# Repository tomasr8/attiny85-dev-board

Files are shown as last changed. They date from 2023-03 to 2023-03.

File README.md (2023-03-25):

# attiny85 development board

<image src="assets/assembled/1.jpg">

<p align="middle">
    <image src="assets/assembled/2.jpg" width="49%">
    <image src="assets/assembled/3.jpg" width="49%">
    <image src="assets/assembled/4.jpg" width="49%">
    <image src="assets/assembled/5.jpg" width="49%">
</p>

## Features

- All 6 GPIOs from the attiny available (marked 0-5 which corresponds to PB0-PB5 on the attiny)
- 5V output (direct from USB)
- 3V3 output (via AMS1117 voltage regulator)
- Power LED
- Onboard LED connected to PB1
- USB-A connector

The schematic is based on the [Digispark attiny85 devboard](assets/digispark-schematic.pdf).

## Why?

To learn more about electronics and PCB design and also because the Digispark boards don't have a 3V3 output. This board also uses USB-A instead of Micro USB so I don't need any extra cable to connect to my laptop. 

## Custom footprints

I use a custom footprint for the USB connector. You'll need to add it to your Kicad footprint library. It's a standard USB-A male connector with through hole connections for easier soldering (exact type is `MOLEX 48037-0001`, available on aliexpress).

<p align="center">
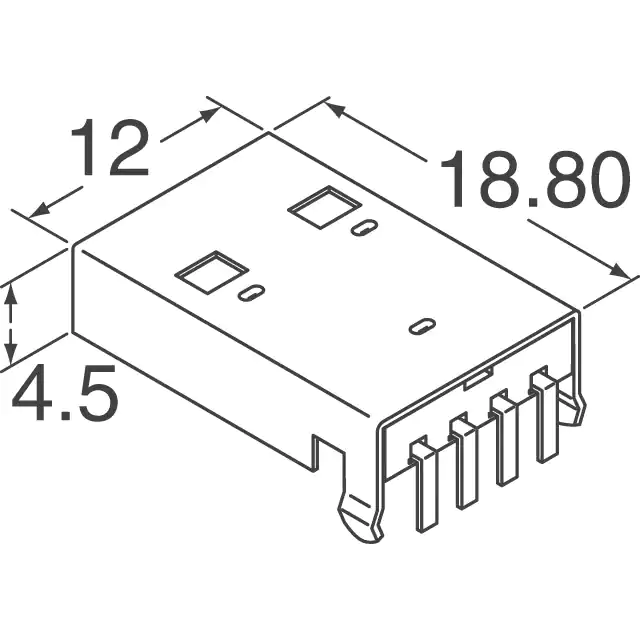
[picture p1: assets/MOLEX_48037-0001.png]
    
</p>

## Bill of materials

All of these components can be easily sourced from aliexpress.

- 2x 470Ω (or similar) resistor (for LEDs)
- 1x Green SMD 1206 LED
- 1x Red SMD 1206 LED
- 2x 66Ω (or similar) resistor (for USB)
- 1x 1K5Ω (or similar) resistor (for USB)
- 2x 3V6 Zener diode (for USB)
- 1x AMS1117 SMD voltage regulator (for 3V3 output)
- 1x IC DIP socket 10-pin (for the attiny)
- 1x attiny85 DIP chip
- 1x 2x5 male or female pin header (breakout connectors)
- 1x USB-A male connector, type MOLEX 48037-0001

## Soldering

I'm not great at soldering SMD components so I recommend starting with those. That would be the LEDs and the voltage regulator. After that you can continue with the chip socket and the pin header. You can finish off with the resistors/diodes and the USB connector.

## Programming

The attiny chip needs to be flashed with a bootloader so that you can use it without a programmer (like an Arduino board).
Here are two tutorials that I used to get mine working (you're gonna need an Arduino board to burn the bootloader):

- https://github.com/Jasdoge/Attiny85-Bootloader-Tutorial
- https://circuitdigest.com/microcontroller-projects/attiny85-ic-programming-through-usb-using-digispark-bootloader

These tutorials use the micronucleus bootloader used by the Digispark attiny boards.

There is an onboard LED hardwired to PB1 so you can get your `blink` sketch running without any extra hardware ;)

## Schematics

<p align="center">
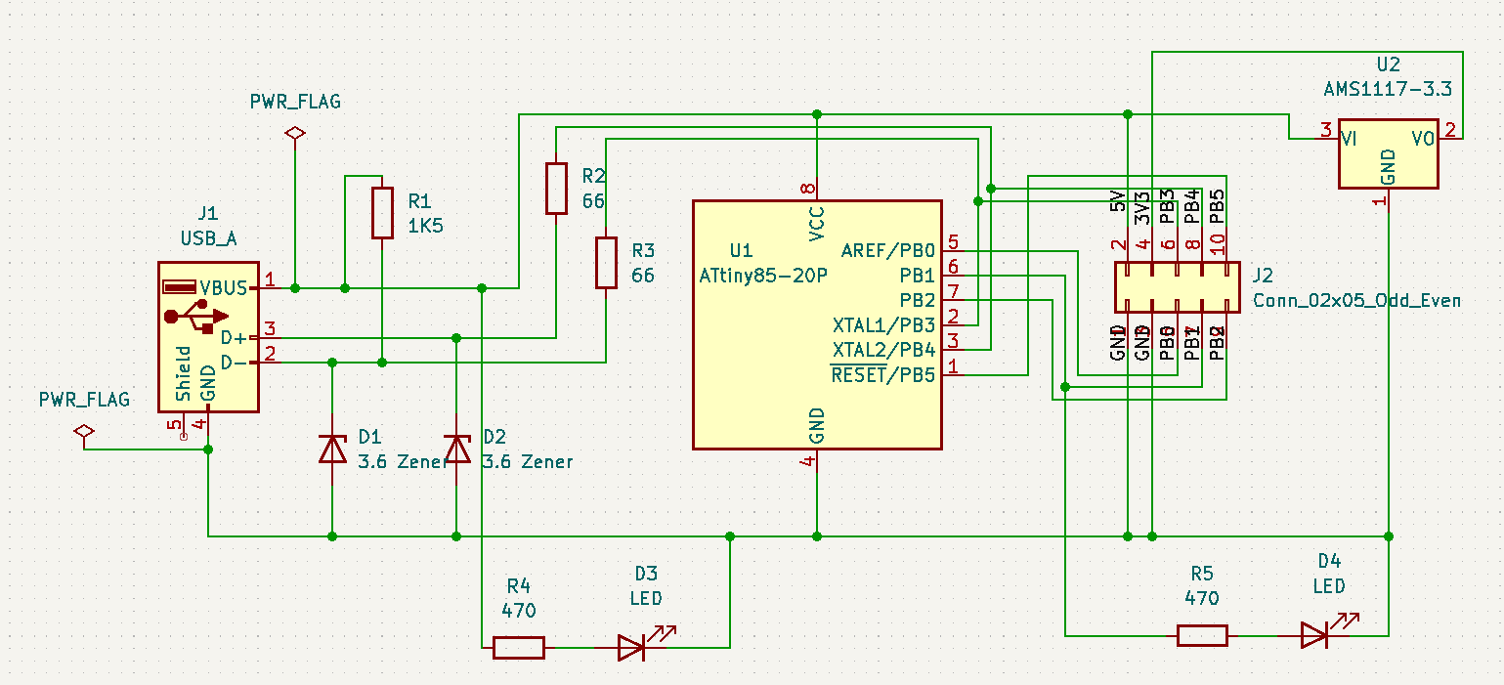
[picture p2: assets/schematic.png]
    
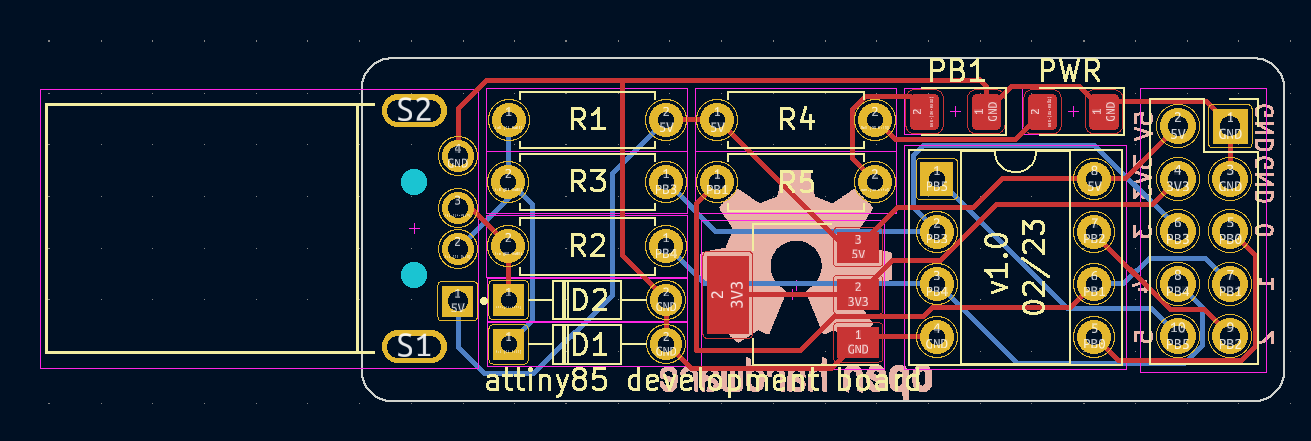
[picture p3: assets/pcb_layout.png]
    
</p>

## Renders

<p align="center">
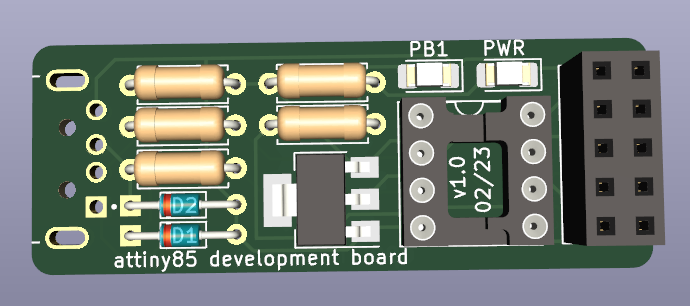
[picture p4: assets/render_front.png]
    
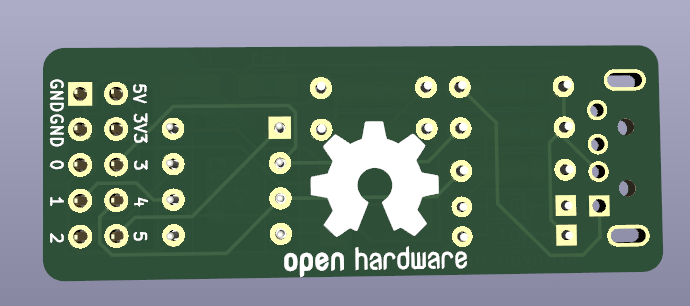
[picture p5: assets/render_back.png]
    
</p>

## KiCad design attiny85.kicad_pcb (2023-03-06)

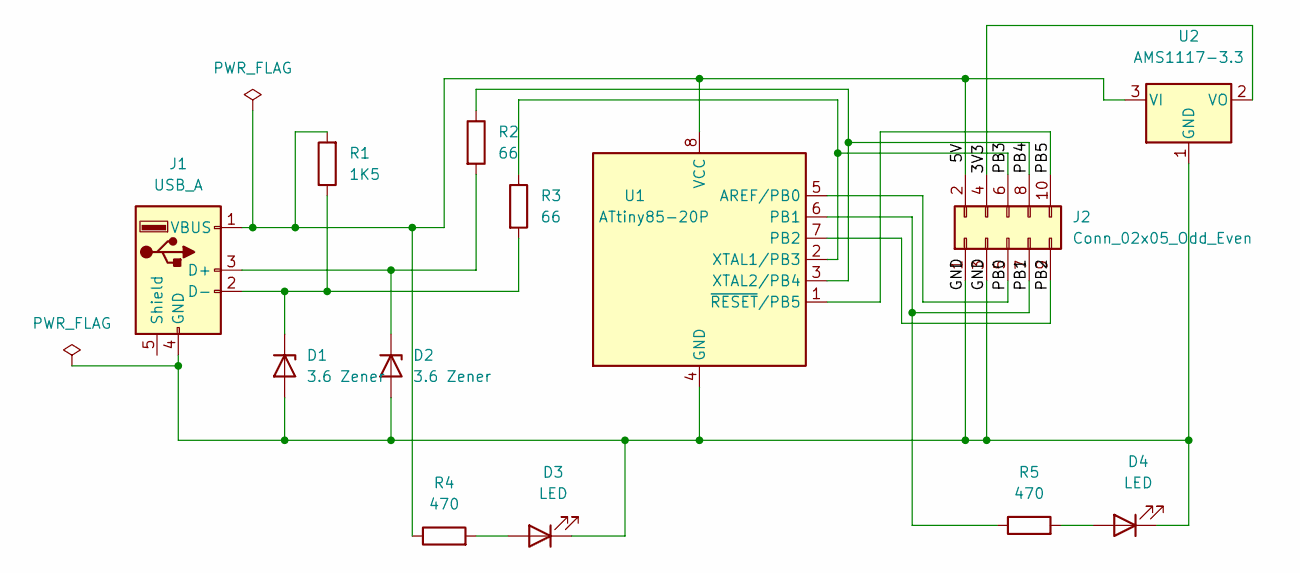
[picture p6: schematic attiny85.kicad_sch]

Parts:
D1, D2: 3.6 Zener; D_DO-34_SOD68_P7.62mm_Horizontal
D3, D4: LED; LED_1206_3216Metric_Pad1.42x1.75mm_HandSolder
J1: USB_A; MOLEX_48037-0001
J2: Conn_02x05_Odd_Even; PinSocket_2x05_P2.54mm_Vertical
R1: 1K5; R_Axial_DIN0207_L6.3mm_D2.5mm_P7.62mm_Horizontal
R2, R3: 66; R_Axial_DIN0207_L6.3mm_D2.5mm_P7.62mm_Horizontal
R4, R5: 470; R_Axial_DIN0207_L6.3mm_D2.5mm_P7.62mm_Horizontal
U1: ATtiny85-20P; DIP-8_W7.62mm_Socket
U2: AMS1117-3.3; SOT-223-3_TabPin2

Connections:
/3V3: J2.4, U2.2 (VO)
/5V: J1.1 (VBUS), J2.2, R1.2, R4.1, U1.8 (VCC), U2.3 (VI)
/GND: D1.2 (A), D2.2 (A), D3.1 (K), D4.1 (K), J1.4 (GND), J2.1, J2.3, U1.4 (GND), U2.1 (GND)
/PB0: J2.5, U1.5 (AREF/PB0)
/PB1: J2.7, R5.1, U1.6 (PB1)
/PB2: J2.9, U1.7 (PB2)
/PB3: J2.6, R3.1, U1.2 (XTAL1/PB3)
/PB4: J2.8, R2.1, U1.3 (XTAL2/PB4)
/PB5: J2.10, U1.1 (~RESET/PB5)
unnamed: D1.1 (K), J1.2 (D-), R1.1, R3.2
unnamed: D2.1 (K), J1.3 (D+), R2.2
unnamed: D3.2 (A), R4.2
unnamed: D4.2 (A), R5.2

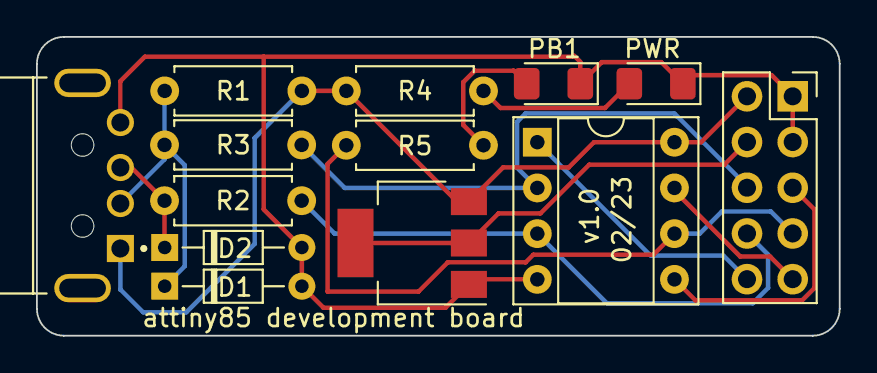
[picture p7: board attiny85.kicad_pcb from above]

Board: 2 copper layers, 44.6 x 16.6 mm, 13 parts (0 on the bottom side), 13 nets.

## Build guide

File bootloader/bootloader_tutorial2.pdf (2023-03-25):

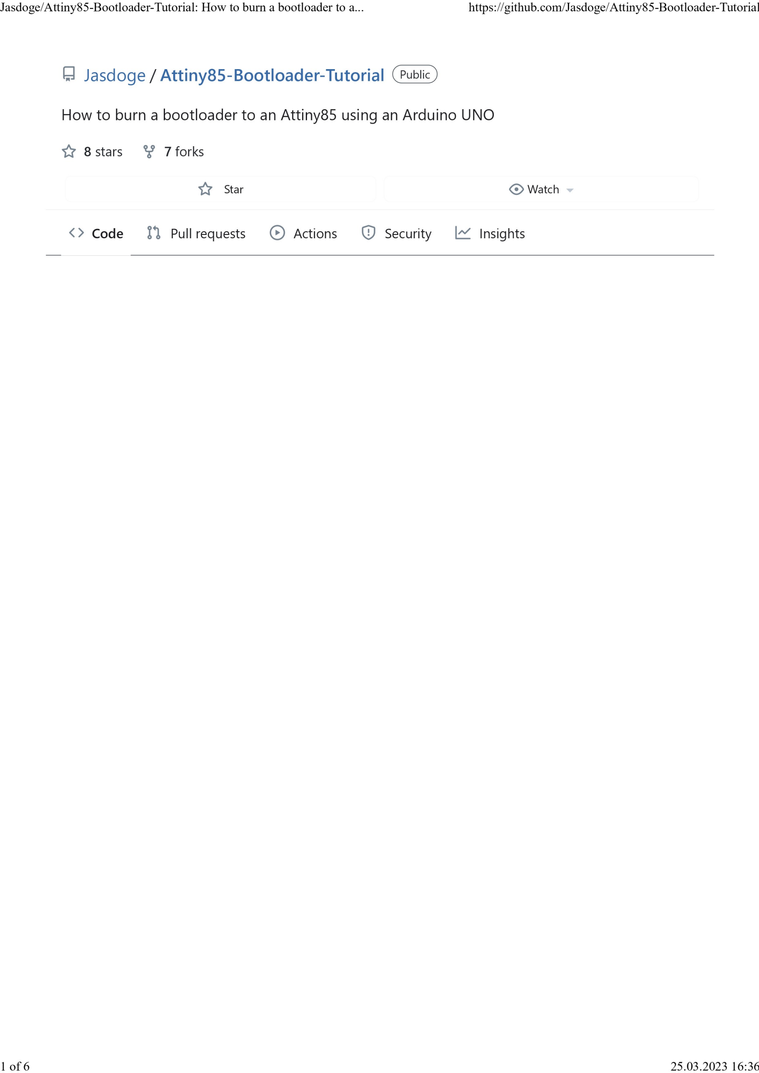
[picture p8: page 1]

Jasdoge / Attiny85-Bootloader-Tutorial Public

How to burn a bootloader to an Attiny85 using an Arduino UNO

### 8 stars 7 forks

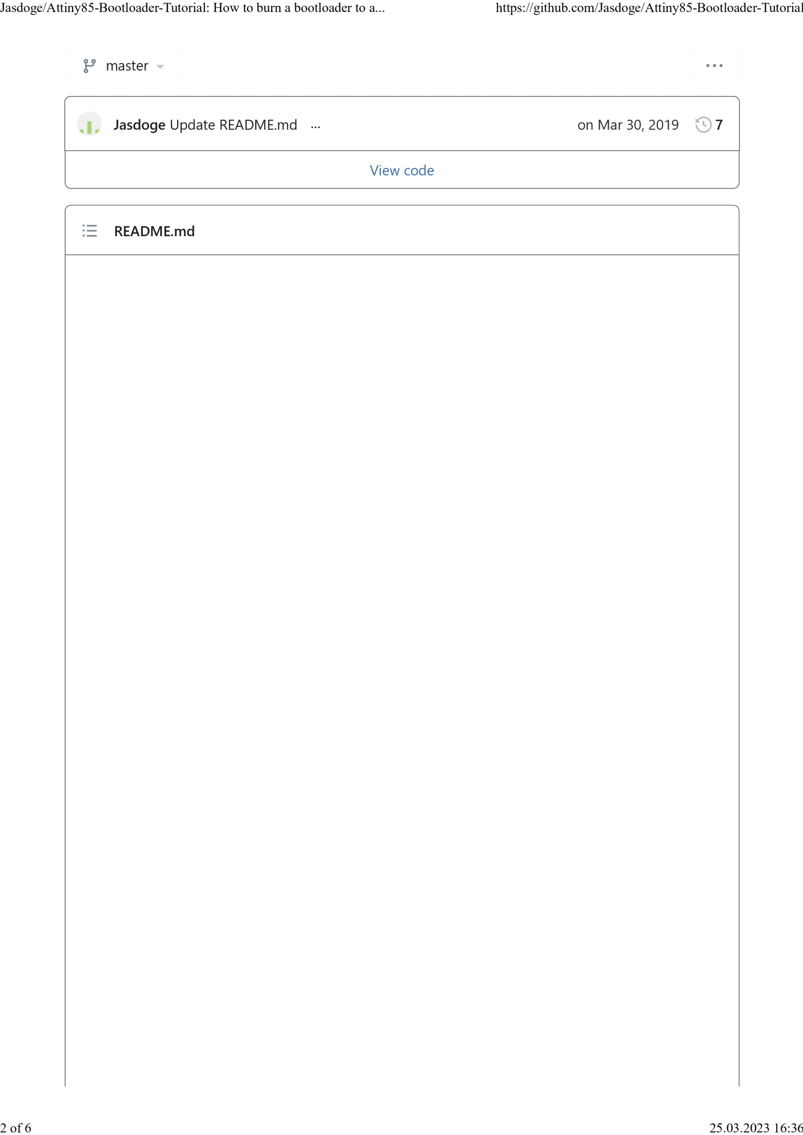
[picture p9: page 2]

View code

Jasdoge/Attiny85-Bootloader-Tutorial: How to burn a bootloader to a... | https://github.com/Jasdoge/Attiny85-Bootloader-Tutorial
3 of 6 | 25.03.2023 16:36

# Attiny85-Bootloader-Tutorial

I recently got one of those cheap chinese attiny USB socket boards and discovered that in order to use the arduino IDE, you need to burn a bootloader onto it. I found a few tutorials online, but a lot of them felt incomplete or included redundant steps.

Video:

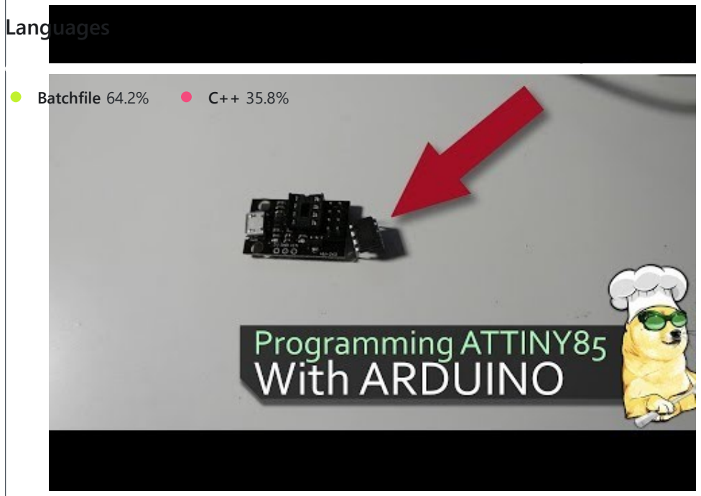
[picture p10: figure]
Languages; Batchfile 64.2%

Here's how to burn a bootloader to an Attiny85 using an Arduino UNO:

### 1. Install the Arduino IDE https://www.arduino.cc/en/Main/Software 2. Install the digistump drivers https://github.com/digistump/DigistumpArduino

/releases
3. Open the arduino IDE and go to file > preferences.

### 4. Add http://digistump.com/package_digistump_index.json to the additional

boards manager URLs.
5. Go to tools > board > boards manager.

Releases

No releases published

Packages

No packages published

4 of 6 | 25.03.2023 16:36

6. Search for digistump, and install Digistump AVR boards.
7. Connect your arduino uno via USB.

### 8. Go to file > examples > 11. ArduinoISP > ArduinoISP to open the ArduinoISP

sketch.
9. Hit the arrow button to upload it to your arduino.

### 10. Unplug your arduino and get your Attiny85, breadboard, some wires, and a 10uF

capacitor.

### 11. Wire the following:

Attiny physical pin | Arduino GPIO/Pin
1 10
4 GND
5 11
6 12
7 13
8 5V

Also connect a 10uF capacitor between arduino RST and arduino GND. If using an electrolytic capacitor, put anode on RST and cathode on GND.

### 12. Connect your arduino again via USB and go into the Arduino IDE. Check what

port it's connected to. In my case it's COM3.

### 13. Edit the burn_attiny85_bootloader.bat file from this repository (right click and

edit). Edit the part that says -PCOM22 to match your port. In my case since I use COM3, I'll edit it to -PCOM3

### 14. Save and copy both the bat file and t85_default.hex to your arduino install

directory.
15. Run the bat file, and it should now burn the bootloader to your attiny85.

# Uploading via arduino

After adding the bootloader, you can now upload via arduino. There's a testsketch in this repo if you just want to blink the debug LED.

1. Write your sketch as usual.

### 2. Connect your attiny to your USB socket board. But don't plug it to the computer

yet.

5 of 6 | 25.03.2023 16:36

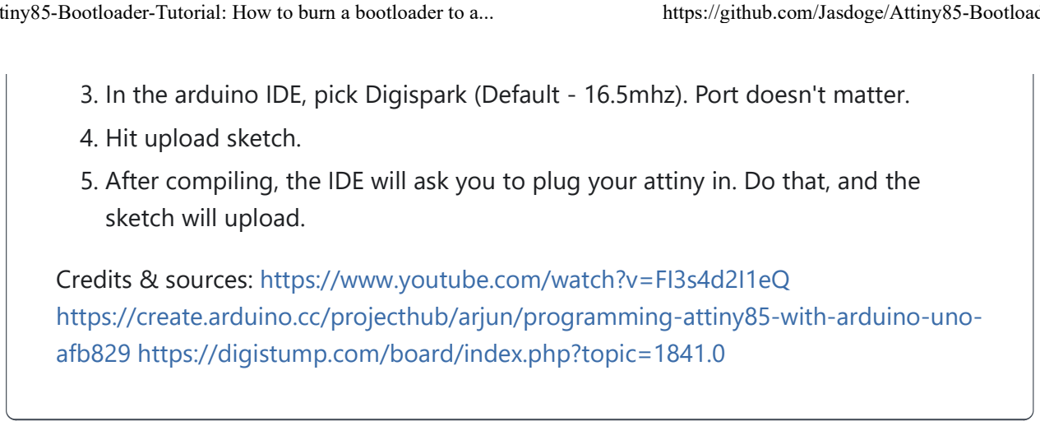
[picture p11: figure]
4. Hit upload sketch.; sketch will upload.; Credits & sources: https://www.youtube.com/watch?v=FI3s4d2I1eQ https://create.arduino.cc/projecthub/arjun/programming-attiny85-with-arduino-uno- afb829 https://digistump.com/board/index.php?topic=1841.0

3. In the arduino IDE, pick Digispark (Default - 16.5mhz). Port doesn't matter.

### 5. After compiling, the IDE will ask you to plug your attiny in. Do that, and the

6 of 6 | 25.03.2023 16:36

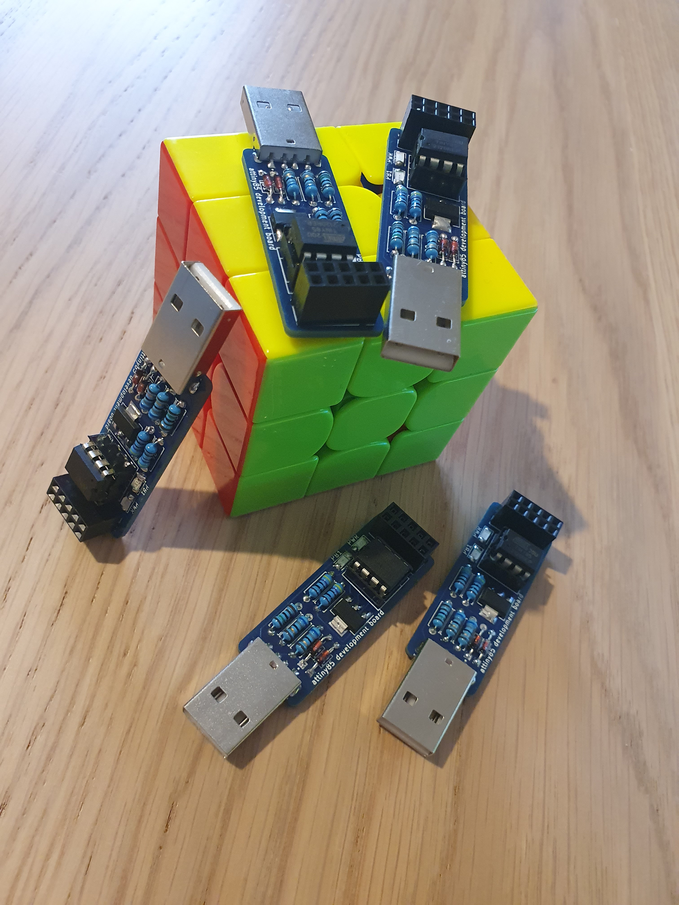
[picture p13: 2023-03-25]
assets/assembled/1.jpg

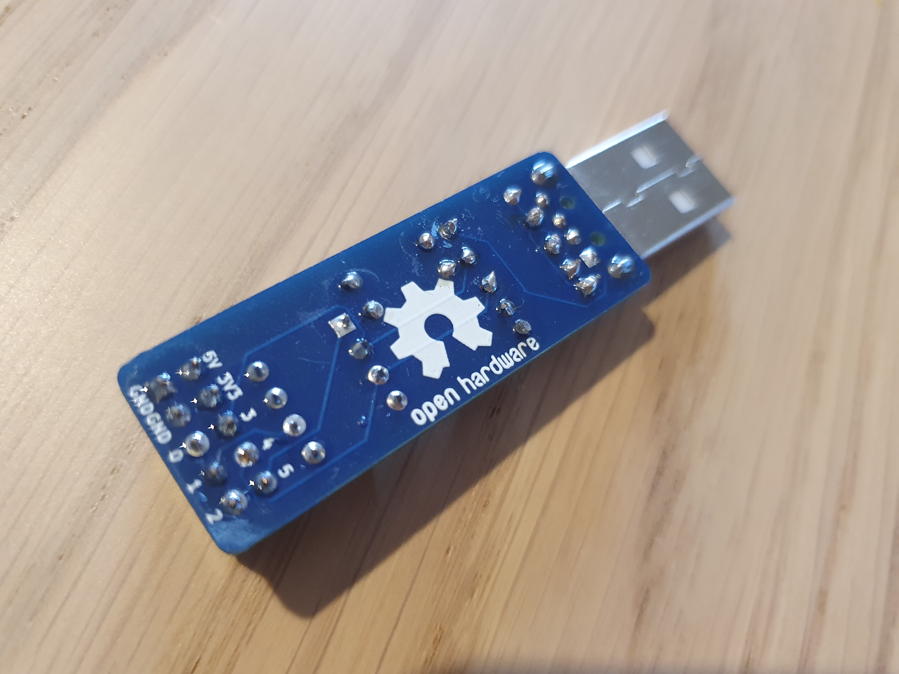
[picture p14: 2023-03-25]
assets/assembled/3.jpg

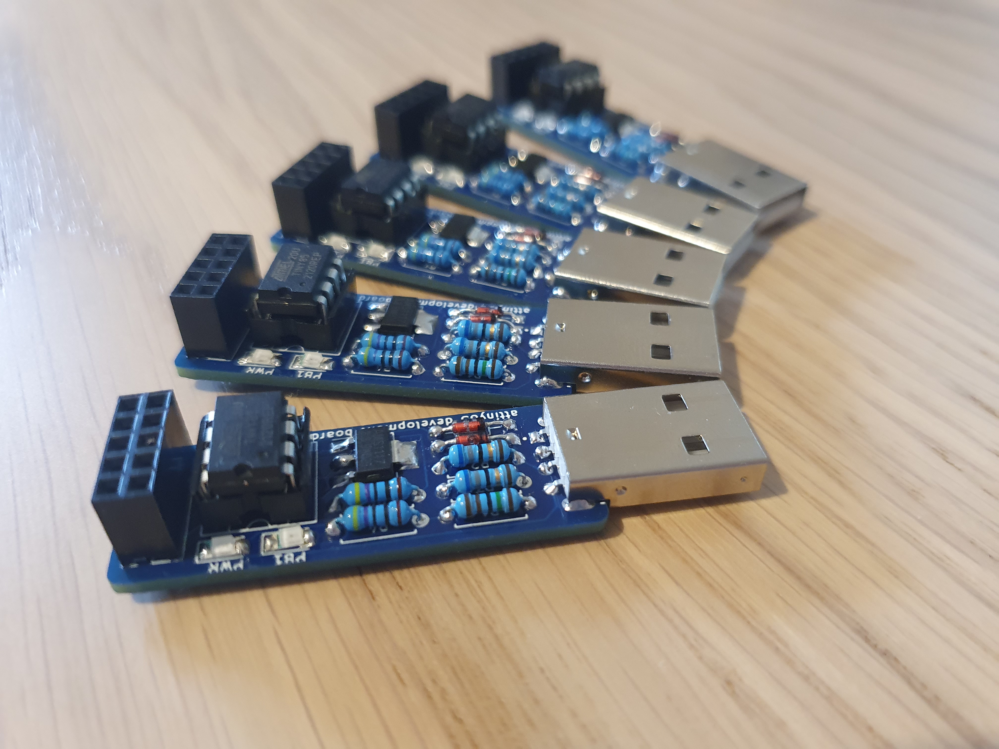
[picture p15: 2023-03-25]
assets/assembled/4.jpg

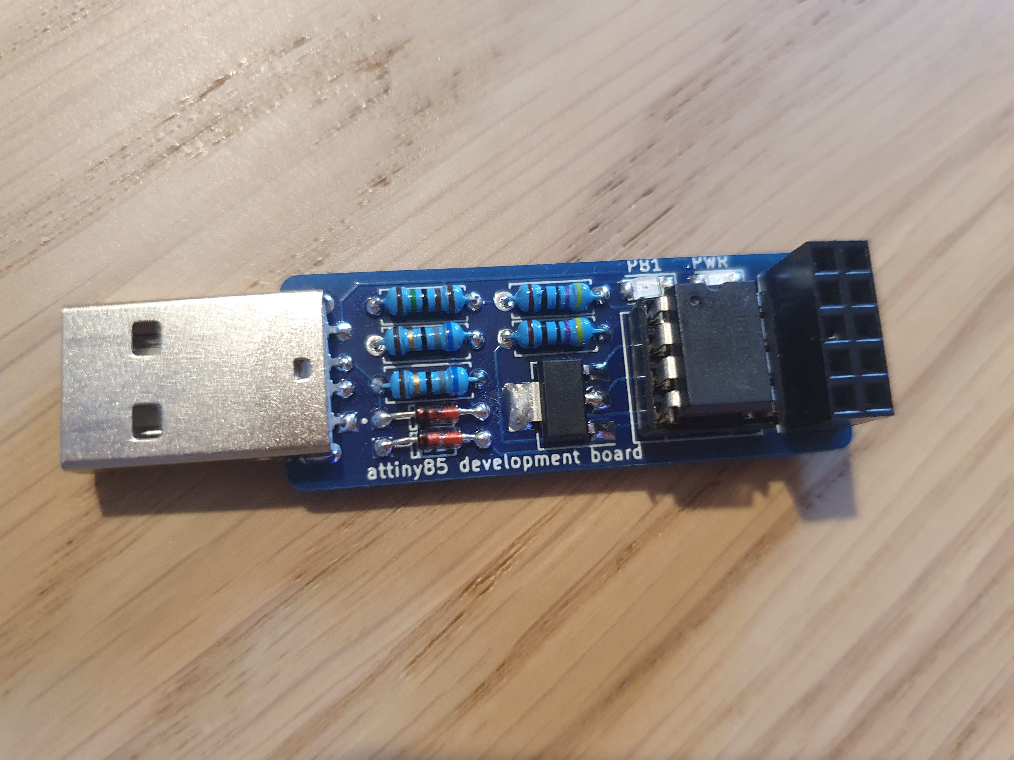
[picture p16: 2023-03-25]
assets/assembled/2.jpg
